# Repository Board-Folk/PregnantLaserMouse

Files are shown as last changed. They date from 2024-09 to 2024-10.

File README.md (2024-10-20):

# Amiga Pregnant Laser Mouse
 An optical mouse replacement pcb for the Amiga pregnant mouse

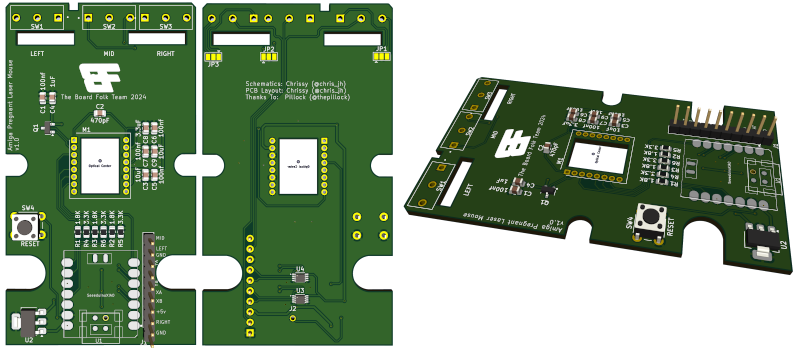
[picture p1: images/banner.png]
PCB
 

Version 1.1

Removed the solder bridges, and just allow gnd on both sides of the switch.

Version 1.0

Requires an XAIO SAMD21 and a ADNS9800 Laser, which you can get still get from Aliexpress. Make sure to also get the Lens.

## Notes

This is for the version 1.0 of the board. v1.1 don't need to do this apart from making sure your switches are the correct way for 2 or 3 button mouse.

In commodore's wisdom, there are differences in the mouse button pcb layput between the 2 button and 3 button versions.
By default i have set the orientation in the 2 button version, as i did not have access to the 3 button pcb layout and they looked identical from the top.

* JP1 - Left Mouse Button Orientation
* JP2 - Middle Mouse Button Orientation
* JP3 - Right Mouse Button Orientation

These are the jumpers underneath the board. Break the traces between the 1st and 2nd pad, and solder between the 2nd pad and 3rd, if you want to use 3 button mouse version.

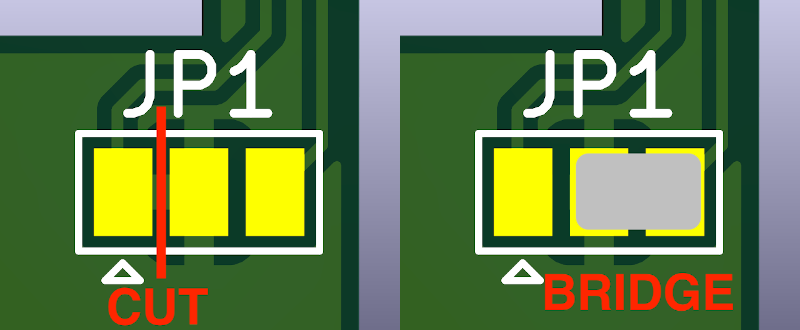
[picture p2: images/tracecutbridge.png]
Mouse Button Trace Cut Bridge


I will probably make a Version 1.1, and join both anyway and if someone finds a switch that is not compatible, to cut the one not needed.

Make sure that you put the switches in the correct orientation also on the PCB that they alignup and hit the tab on the button before soldering.

## Bom

[**SMD Interactive BOM**][IBOMSMD]

[Gerbers 1.1 ](https://github.com/Board-Folk/PregnantLaserMouse/blob/main/production/Amiga_Pregnant_Laser_Mouse_1.1.zip)

[Gerbers 1.0 with solder bridges](https://github.com/Board-Folk/PregnantLaserMouse/blob/main/production/Amiga_Pregnant_Laser_Mouse_1.0.zip)

<a href="https://www.pcbway.com/project/shareproject/Amiga_Pregnant_Laser_Mouse_bde463a2.html">PCB from PCBWay</a>

Software [see here](https://github.com/Board-Folk/PregnantLaserMouse/tree/main/SW)

## 3D Printable Mouse

A fully printable Amiga pregnant Mouse is available here

[Amiga - "Pregnant" Mouse (3-button)](https://www.pcbway.com/project/shareproject/Amiga_Pregnant_Mouse_3_button_version_f910c5ea.html)

This project also includes varient for the optical ADNS 9800

* Shell - Bottom (Laser variant)
* Shell - Top
* Shell - Buttons

## 3D Printable Lens Cover for the Original Mouse

3D Printable Lens Cover (lens.stl) still requires testing, Sketchup model file is included to modify for tolerances of your printer.

***Print Settings***

* Layer Height : 1.5mm
* Print Speed : 25 mm/s
* Initial Layer Speed: 15mm
* Support: Yes
* Infill: 20%
* Line Width: 0.4mm
* Print Thin Walls: Yes
* Filter Out Tiny Gaps: Yes

## 3D Printable PCB Holder

The (holder.stl) is just to well, hold the PCB in place. May or may not be needed.

## Thanks

  * Pillock ([@thepillock])
&nbsp;
  * The rest of the Board Folk Team for their support and general
    coolness.\
&nbsp;
  * ADNS9800 interface based on code from https://github.com/mrjohnk/ADNS-9800
  * QUADRATURE interface based on blog from http://danceswithferrets.org/geekblog/?p=742

## !!!!! WARNING !!!!!
Don't Plug in the USB to the XAIO while connected to the Amiga/Computer, as this will join the 5V together and may damage something.

This is still a work in progress, use at your own risk. I accept no responsibility if this damages any of your equipment.

[IBOMSMD]: http://htmlpreview.github.io/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

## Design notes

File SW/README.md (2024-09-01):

# Arduino IDE Software

Installing the Pre Built UF2
--

I have prebuilt the UF2 file in the build folder, connect the XAIO board to your computer, and double press reset on the board.

A Drive should appear usually named Arduino, copy the UF2 file to this drive, the drive will then disconnect, and sofware should be uploaded.

(Same method as using a Pi Pico)

Building the software
--

1. Open the arduino sketch PregnantLaserMouse
2. Make sure you have the Seeduino XIAO board selected
	* If not guide is here from XIAO (https://wiki.seeedstudio.com/Seeeduino-XIAO/)
3. You should be able to compile and upload to the XIAO Board, if you have connected via USB and selected the comm port

Building the UF2
--

1. Click "Sketch" in the menu, and select "Export Compiled Binary"
2. Open the PregnantLaserMouse folder and there should be a build folder with a bin file. This file needs converting to uf2, see below.

Converting bin to uf2 for SAMD21
--

1. Download the Microsoft uf2 tool from the official site to your local drive somewhere and keep a note:

``
$ git clone https://github.com/microsoft/uf2.git
``

2. Navigate to the build directory in command line:

``
$ cd {SOMEWHERE}/PregnantLaserMouse/SW/PregnantLaserMouse/build/Seeeduino.samd.seeed_XIAO_m0
``

3. Run the uf2conv.py python script in this location as follow:

``
$ python {SOMEWHERE}/uf2/utils/uf2conv.py -f 0x68ed2b88 -b 0x2000 ./PregnantLaserMouse.ino.bin -o ./PregnantLaserMouse.ino.uf2
``

_Note: -f 0x68ed2b88 is for SAMD21 and -b 0x2000 is used for base address._

4. Plug in the XIA via USB-c into your computer, it should appear as a flash drive.

5. Simply drag the flash.uf2 into the XIAO flash drive.

6. Done

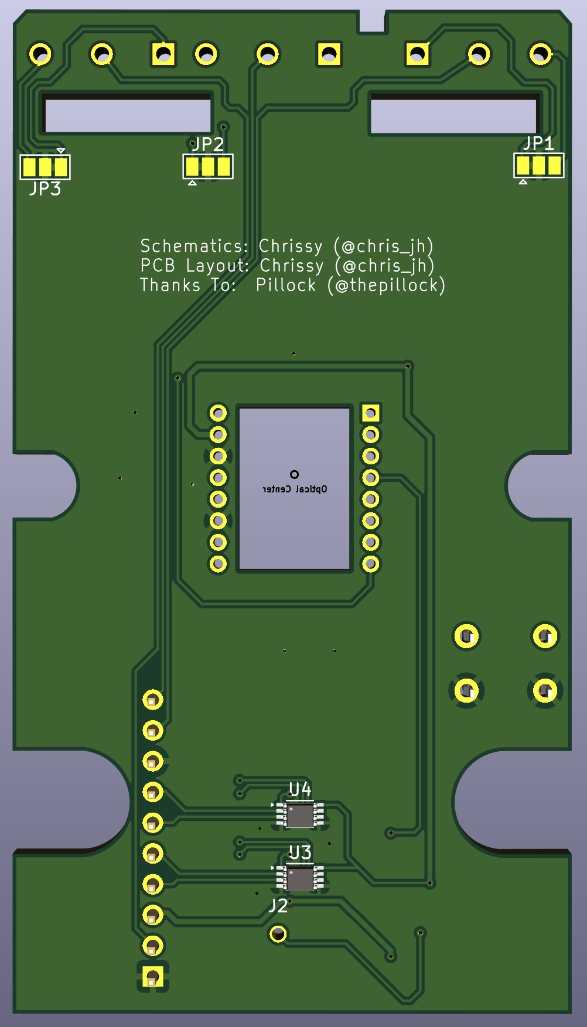
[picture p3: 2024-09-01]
images/back.png

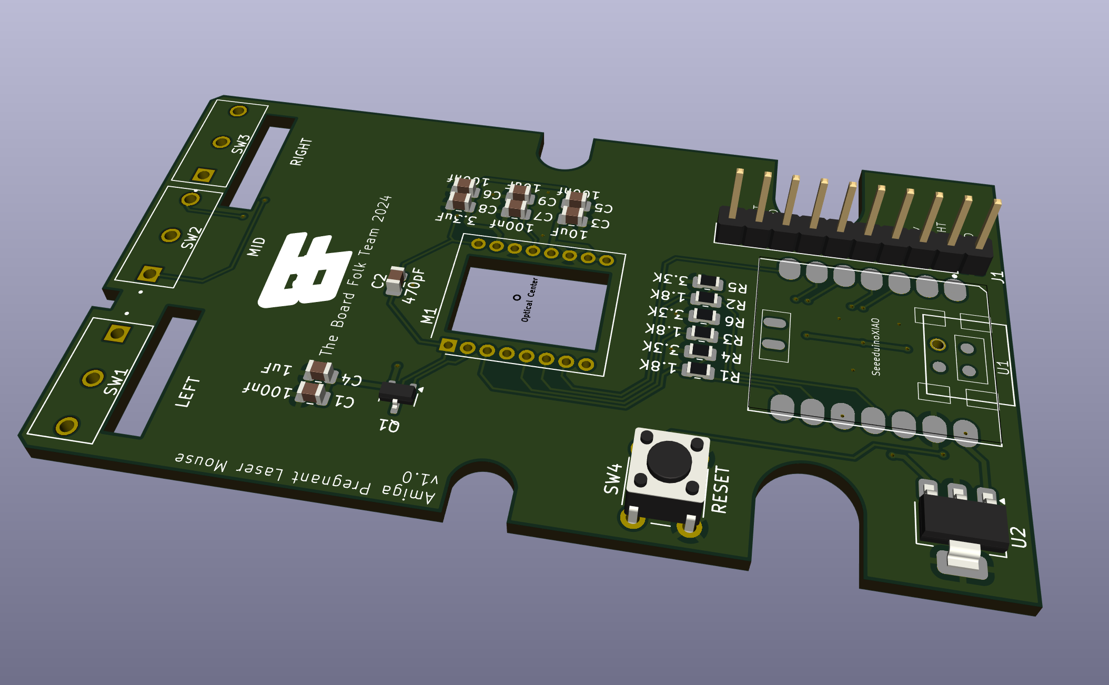
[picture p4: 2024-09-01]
images/main.png

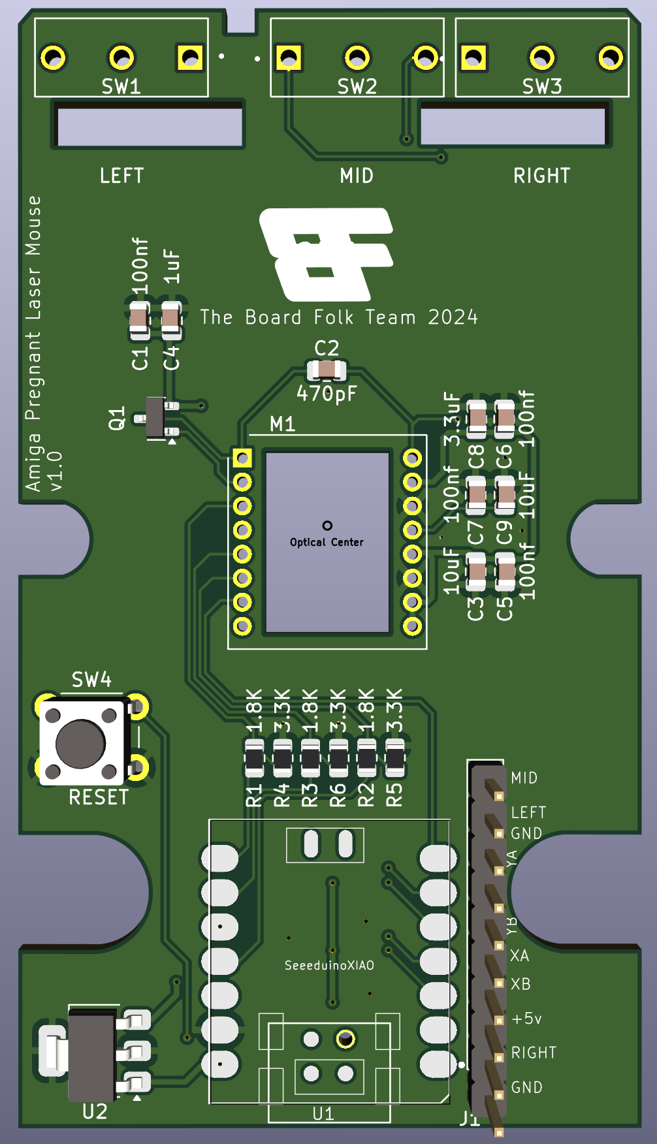
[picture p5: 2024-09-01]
images/front.png

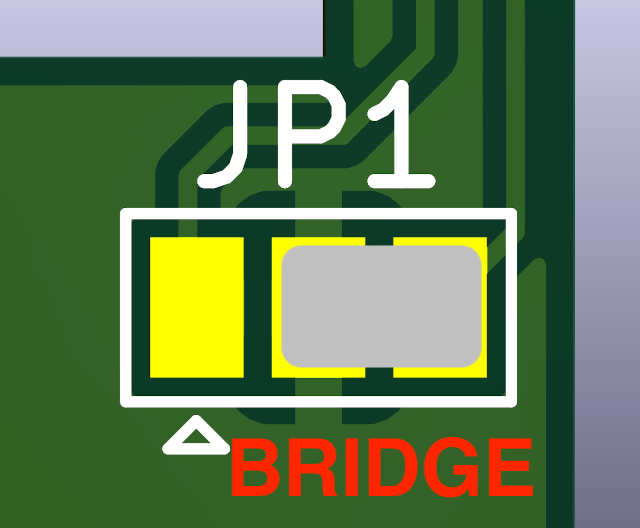
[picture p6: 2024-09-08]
images/trace2.png

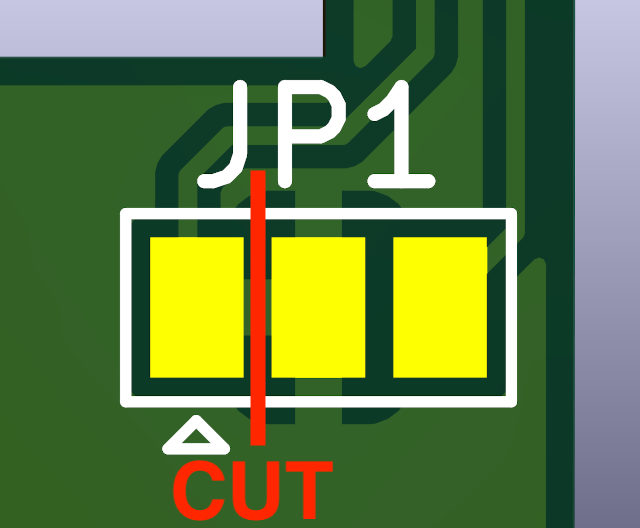
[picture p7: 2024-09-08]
images/trace1.png

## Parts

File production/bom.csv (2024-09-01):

Designator | Footprint | Quantity | Value | LCSC Part #
C1, C5, C6, C7 | 0805 | 4 | 100nf
C2 | 0805 | 1 | 470pF
C3, C9 | 0805 | 2 | 10uF
C4 | 0805 | 1 | 1uF
C8 | 0805 | 1 | 3.3uF
J1 | PinHeader_1x10_P2.54mm_Vertical | 1 | Amiga_Conn
M1 | ADNS-9800 | 1 | ADNS-9800
Q1 | SOT-23 | 1 | IRLML6302TRPBF
R1, R2, R3 | 0805 | 3 | 1.8K
R4, R5, R6 | 0805 | 3 | 3.3K
SW1 | SW_D2F-01F | 1 | LEFT
SW2 | SW_D2F-01F | 1 | MID
SW3 | SW_D2F-01F | 1 | RIGHT
SW4 | SW_PUSH_6mm_H4.3mm | 1 | RESET
U1 | Seeeduino XIAO-MOUDLE14P-2.54-21X17.8MM | 1 | SeeeduinoXIAO
U2 | SOT-223-3_TabPin2 | 1 | LT1963AxST-3.3
U3, U4 | VSSOP-8_2.3x2mm_P0.5mm | 2 | 74LVC2T45DC

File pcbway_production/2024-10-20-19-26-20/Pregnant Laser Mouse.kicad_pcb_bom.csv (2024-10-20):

Designator | Quantity | Value | Footprint | Package | MPN | DNP | Mount_Type | Digikey | Description
C1, C5, C6, C7 | 4 | 100nf | C_0805_2012Metric |  |  |  | smt | 399-C0805C104K5RAC7210CT-ND
C2 | 1 | 470pF | C_0805_2012Metric |  |  |  | smt | 399-C0805C471K5RAC7800CT-ND
C3, C9 | 2 | 10uF | C_0805_2012Metric |  |  |  | smt | 399-C0805C106K8PAC7800CT-ND
C4 | 1 | 1uF | C_0805_2012Metric |  |  |  | smt | 399-C0805C105K4RAC7800CT-ND
C8 | 1 | 3.3uF | C_0805_2012Metric |  |  |  | smt | 399-C0805C335K8PAC7800CT-ND
J1 | 1 | Amiga_Conn | PinHeader_1x10_P2.54mm_Vertical |  |  |  | tht | 2057-PH1-10-UA-ND | Generic connector, single row, 01x10, script generated (kicad-library-utils/schlib/autogen/connector/)
J2 | 1 | Reset Hole | ResetHole |  |  | Yes | tht |  | Generic connector, single row, 01x01, script generated (kicad-library-utils/schlib/autogen/connector/)
M1 | 1 | ADNS-9800 | ADNS-9800 |  |  |  | tht | Aliexpress Get Lens Also
Q1 | 1 | IRLML6302TRPBF | SOT-23 |  |  |  | smt | IRLML6302PBFCT-ND / DMG2301LK-7DICT-ND
R1, R2, R3 | 3 | 1.8K | R_0805_2012Metric |  |  |  | smt | 2019-RK73H2ATTD1801FCT-ND
R4, R5, R6 | 3 | 3.3K | R_0805_2012Metric |  |  |  | smt | 2019-RK73H2ATTD3301FCT-ND
SW1 | 1 | LEFT | SW_D2F-01F |  |  |  | tht | SW501-ND
SW2 | 1 | MID | SW_D2F-01F |  |  |  | tht | SW501-ND
SW3 | 1 | RIGHT | SW_D2F-01F |  |  |  | tht | SW501-ND
SW4 | 1 | RESET | SW_PUSH_6mm_H4.3mm |  |  |  | tht | 450-1650-ND | Omron B3FS 6x6mm single pole normally-open tactile switch
U1 | 1 | SeeeduinoXIAO | Seeeduino XIAO-MOUDLE14P-2.54-21X17.8MM |  |  |  | smt | 1597-102010328-ND
U2 | 1 | LT1963AxST-3.3 | SOT-223-3_TabPin2 |  |  |  | smt | AP7361C-33E-13DICT-ND | 3.3V, 1.5A, Low Noise, Fast Transient Response LDO Regulator, SOT-223
U3, U4 | 2 | 74LVC2T45DC | VSSOP-8_2.3x2mm_P0.5mm |  |  |  | smt | 1727-4578-1-ND | Dual supply translating transceiver, 3-state, 2-bit, VSSOP-8

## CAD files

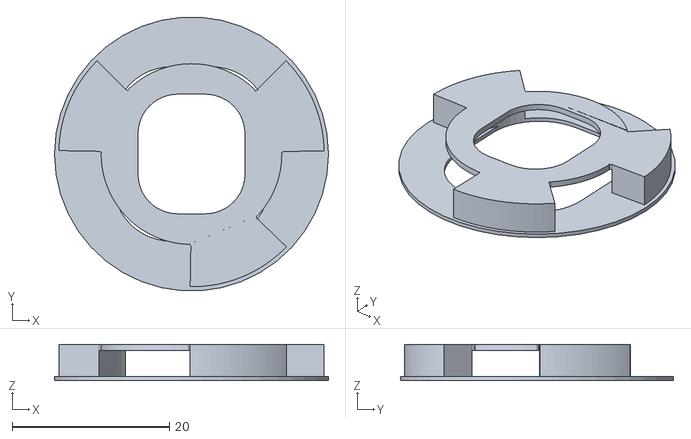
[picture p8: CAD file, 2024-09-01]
lens/lens.stl
34.9 x 34.8 x 4.60

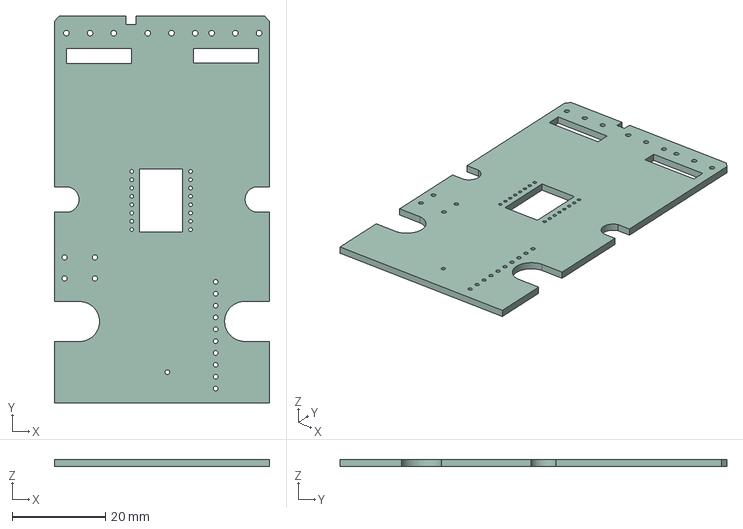
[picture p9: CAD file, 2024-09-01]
Pregnant Laser Mouse.step
46.2 x 83.0 x 1.60 mm

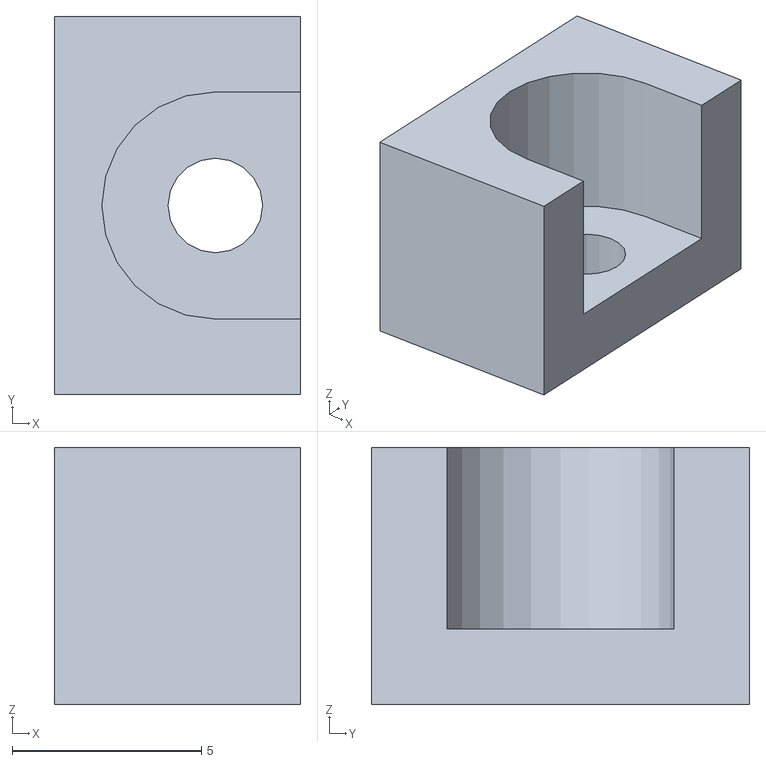
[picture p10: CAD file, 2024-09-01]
lens/holder.stl
6.50 x 10.0 x 6.80

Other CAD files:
lens/lens.skp

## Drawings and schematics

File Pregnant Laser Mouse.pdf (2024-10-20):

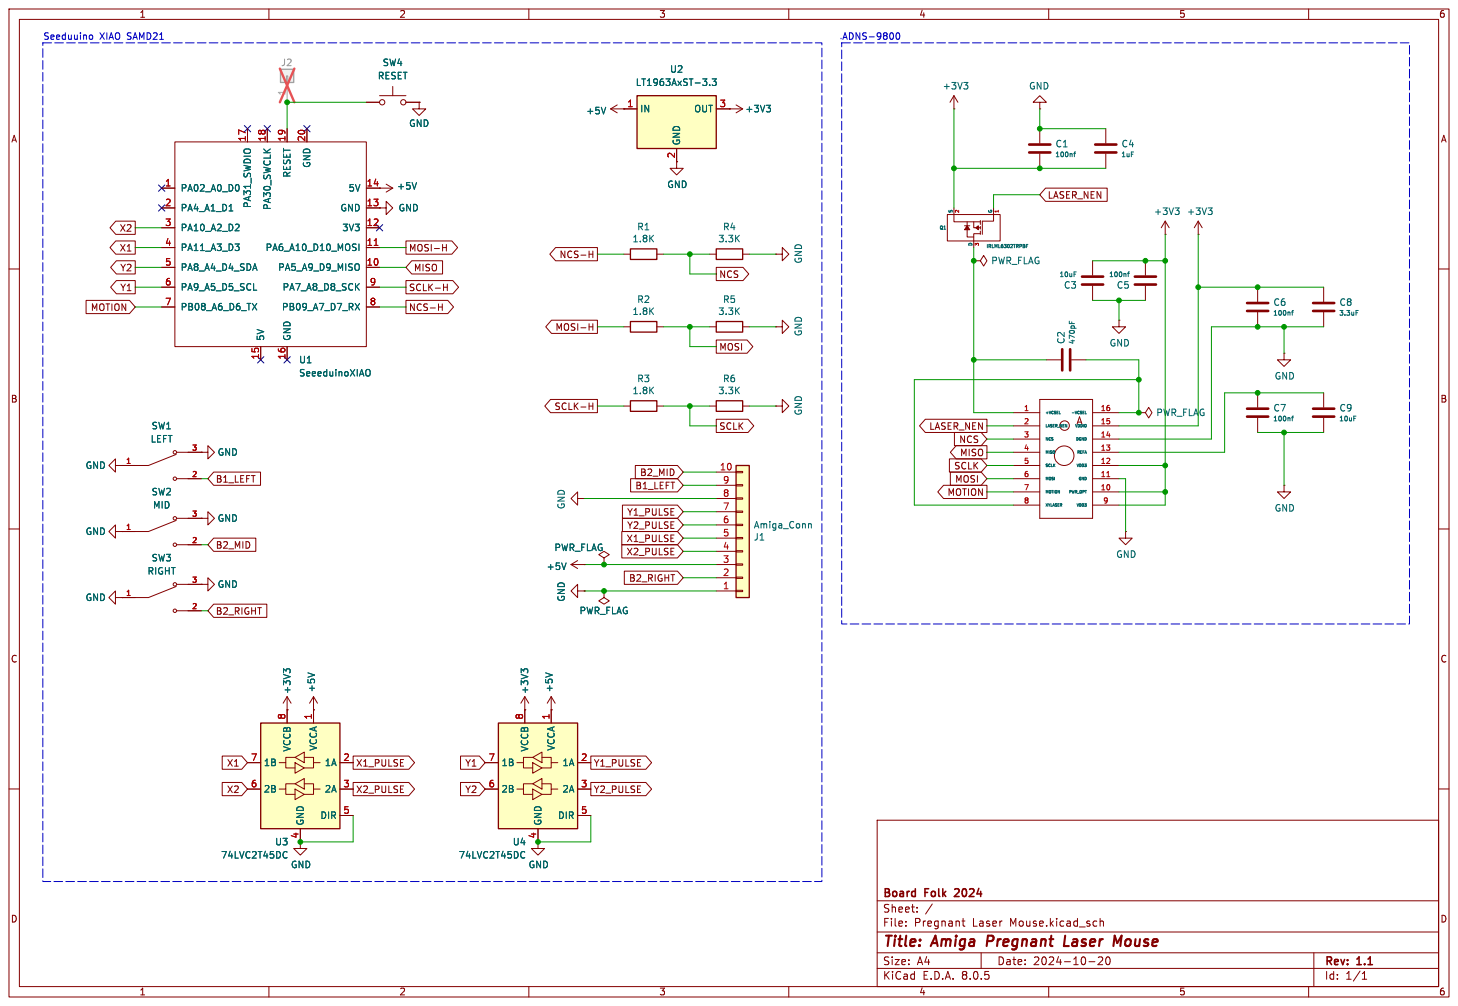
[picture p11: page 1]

Id: 1/1 Title: Amiga Pregnant Laser Mouse

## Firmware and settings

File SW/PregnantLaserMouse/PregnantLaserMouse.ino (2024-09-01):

/*
 * Pregnant Laser Mouse
 * By Chrissy
 * Version 1.0
 * Copyright 2024
 * 
 * ADNS9800 interface based on code from https://github.com/mrjohnk/ADNS-9800
 * QUADRATURE interface based on blog from http://danceswithferrets.org/geekblog/?p=742
 * 
 * 
 * !!!!! WARNING !!!!!
 * 
 * Don't Plug in the USB to the Arduino while connected to the Amiga/Computer, as this will join the 5V together and may damage something.
 * 
 * !!!!! WARNING !!!!!
 * 
 */

#include <SPI.h>
#include <SPI.h>
#define PIN_NCS    7
#define PIN_MOTION 6

//AMIGA PIN OUT
#define PIN_XB   2 //AMIGA PIN 4
#define PIN_XA   3 //AMIGA PIN 5
#define PIN_YB   4 //AMIGA PIN 6
#define PIN_YA   5 //AMIGA PIN 7

//MOTION SPEED CONTROL
//#define FAST //UNCOMMENT TO MAKE AS FAST AS POSSIBLE
unsigned long delayX = 0;
unsigned long delayY = 0;
const unsigned long delayBy = 100; //ALTER THIS TO CHANGE MOUSE SPEED, HIGHER NUMBER SLOWER

//QUADRATURE INDEXING (PULSES)
const bool chan1[] = {HIGH, HIGH, LOW, LOW};
const bool chan2[] = {HIGH, LOW, LOW, HIGH};
signed int xIndex, yIndex = 0;

void setup() {
  delay(2000);
  Serial.begin(9600);
  setupSPI();
  if (setupADNS()){
    setupQuadrature();
    #ifdef FAST
      attachInterrupt(PIN_MOTION, readMotion, FALLING); //Not sure to have this, or just read in loop
    #endif
  }
}

void setupSPI(){
  Serial.println("Init SPI");
  pinMode(PIN_NCS, OUTPUT);
  pinMode(PIN_MOTION, INPUT_PULLUP); 
  //digitalWrite(PIN_NCS, HIGH); // disable Slave Select

  SPI.begin();
  SPI.setDataMode(SPI_MODE3);
  SPI.setBitOrder(MSBFIRST);
  SPI.setClockDivider(SPI_CLOCK_DIV8);
  delay(100);
}

//SETUP THE QUADRATURE
void setupQuadrature() {
  Serial.println("Init Quadrature");
  pinMode(PIN_XA, OUTPUT);
  pinMode(PIN_XB, OUTPUT);
  pinMode(PIN_YA, OUTPUT);
  pinMode(PIN_YB, OUTPUT);
  digitalWrite(PIN_XA, HIGH);
  digitalWrite(PIN_XB, HIGH);
  digitalWrite(PIN_YA, HIGH);
  digitalWrite(PIN_YB, HIGH);
}

void loop() {
  #ifndef FAST
    readMotion();
  #endif
}


//READ THE MOUSE MOTION ON HOW FAR IT HAS CURRENTLY TRAVELLED AND PULSE THE AMIGA THE DISTANCE
void readMotion(){
  volatile int* xydat = readADNS();
  signed int mX = convTwosComp(xydat[1]);
  signed int mY = convTwosComp(xydat[3]);
  pulse(mX, mY);
}

//PULSE THE AMIGA
void pulse(signed int mX, signed int mY){
  bool rX = (mX <= 0); //Check Reverse
  bool rY = (mY <= 0); //Check Reverse

  mX = abs(mX); //Make it positive
  mY = abs(mY); //Make it positive

  while (mX || mY) { //May Need Timer Delays ??????
    if (mX > 0 && doX()){
      xIndex = (rX ? xIndex + 1 : xIndex - 1);
      if (xIndex < 0) xIndex = 3; else if (xIndex > 3) xIndex = 0;
      mX--;
      pulseX(xIndex);
    }

    if (mY > 0 && doY()){
      yIndex = rY ? yIndex + 1 : yIndex - 1;
      if (yIndex < 0) yIndex = 3; else if (yIndex > 3) yIndex = 0;
      mY--;
      pulseY(yIndex);
    } 
  }
  readADNS(); //Clear ADNS Buffer ready for new read
}

//PULSE THE QUADRATURE X
void pulseX(signed int index) {
  digitalWrite(PIN_XA, chan1[index]);
  digitalWrite(PIN_XB, chan2[index]);
}

//PULSE THE QUADRATURE Y
void pulseY(signed int index) {
  digitalWrite(PIN_YA, chan1[index]);
  digitalWrite(PIN_YB, chan2[index]);
}

//UTILS
int convTwosComp(int b){
  if(b & 0x80){
    b = -1 * ((b ^ 0xff) + 1);
  }
  return b;
}

bool doX(){
  #ifdef FAST
    return true;
  #else
    if ((micros() > delayX)){
      delayX = micros() + delayBy;
      return true;
    }
    return false;
  #endif
}

bool doY(){
  #ifdef FAST
    return true;
  #else
    if ((micros() > delayY)){
      delayY = micros() + delayBy;
      return true;
    }
    return false;
  #endif
}

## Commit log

2024-09-01 Tidy Up
    Code update
    Silk update
    General Tidy
    [Pregnant Laser Mouse.kicad_sch, holder.stl, lens.skp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]
2024-09-01 pcbway gerbers
2024-09-01 Update Pregnant Laser Mouse.step
    [Pregnant Laser Mouse.step]
2024-09-01 some bom files
    [Pregnant Laser Mouse.kicad_pcb_bom.csv, Pregnant Laser Mouse.kicad_pcb_positions.csv, bom.csv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]
2024-10-20 Update to 1.1
    Removed solder bridges to allow switch to be used on either side without having to cut and rebridge
    [Pregnant Laser Mouse.kicad_pcb_bom.csv, Pregnant Laser Mouse.kicad_pcb_positions.csv, Pregnant Laser Mouse.kicad_sch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]
2024-11-09 Create PregnantLaserMouseSwappedY.uf2
    Added to swap Y, may be issue with PCB YA YB wrong way with original Pregnant Mouse Cable
